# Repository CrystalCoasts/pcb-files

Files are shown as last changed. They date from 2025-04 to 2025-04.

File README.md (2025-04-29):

# Smart Sea Wall PCB Files
Repo for ESP32 Smart Sea Wall PCB and Hardware.  
***

## Table of Contents
- [Introduction](#introduction)
- [Getting Started](#getting-started)
- [Layout](#contains)
- [Bill of Materials](#bill-of-materials)
- [Installation](#installation)

***

## Introduction

We designed and created a PCB for easy recreation of the device. The sensors are plug and play, allowing the user to easily service the device. The file was desgined in KiCAD and printed using JLC PCB.

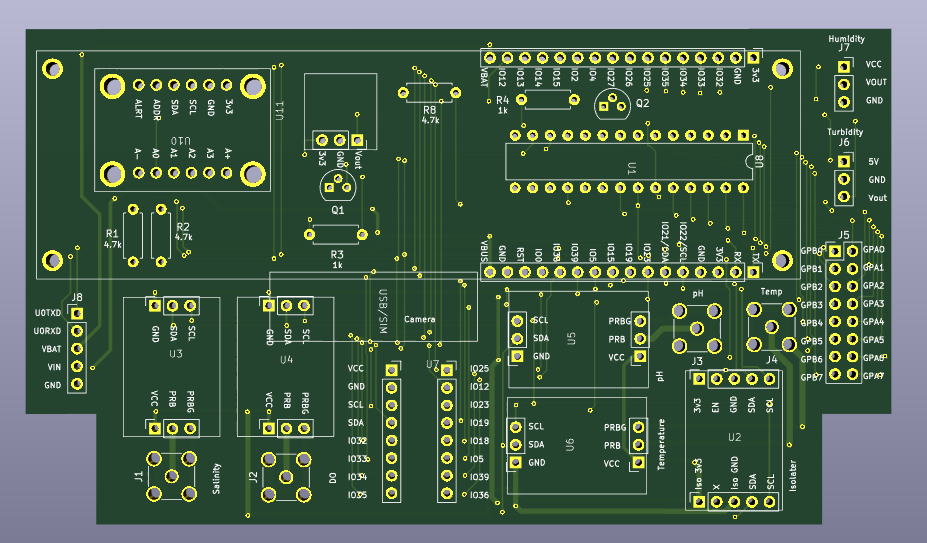
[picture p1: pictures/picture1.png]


***

## Getting Started

 1. Gather all components stated in the [BOM](#bill-of-materials).
 2. Order the PCB through JLCPCB using the already created gerber zip file.
 3. Follow the soldering and installation instructions in the [Instalation](#installation) section.
 4. Test device with the embedded-code repository.

## Bill of Materials

As far as materials go, many you may not be able to find headers the exact size for what you need. In that case, just find the closest one to it and cut it down to size (e.g. cut a 6 pin header to 5 pins), or use multiple to make up the size you need.

 - (8) 3-pin header
 - (4) SMA male connector
 - (2) 16-pin header
 - (2) 8-pin header
 - (1) 5-pin header
 - (2) 8-pin terminals (2.54 pitch)
 - (2) 3-pin terminals (2.54 pitch)
 - (3) 4.7k resistors (7.62 horizontal length)
 - (2) 1k resistors (7.62 horizontal length)
 - (2) bjt transistors (2n2222 or similar)
 - (1) mcp23017 I2C IO extender - [link](https://www.digikey.com/en/products/detail/microchip-technology/MCP23017-E-SP/894272)
 - (1) Boost converter - [link](https://a.co/d/0dH0B8B)
 - (1) I2C ADC - [link](https://www.adafruit.com/product/1083)
 - (1) Lilygo ESP32 T-7000G - [link](https://lilygo.cc/products/t-sim7000g?srsltid=AfmBOoofkf4orIAGPrCQvzU6p47uRy_uEcURHfCpysc8IG0x-OTQUHQe)

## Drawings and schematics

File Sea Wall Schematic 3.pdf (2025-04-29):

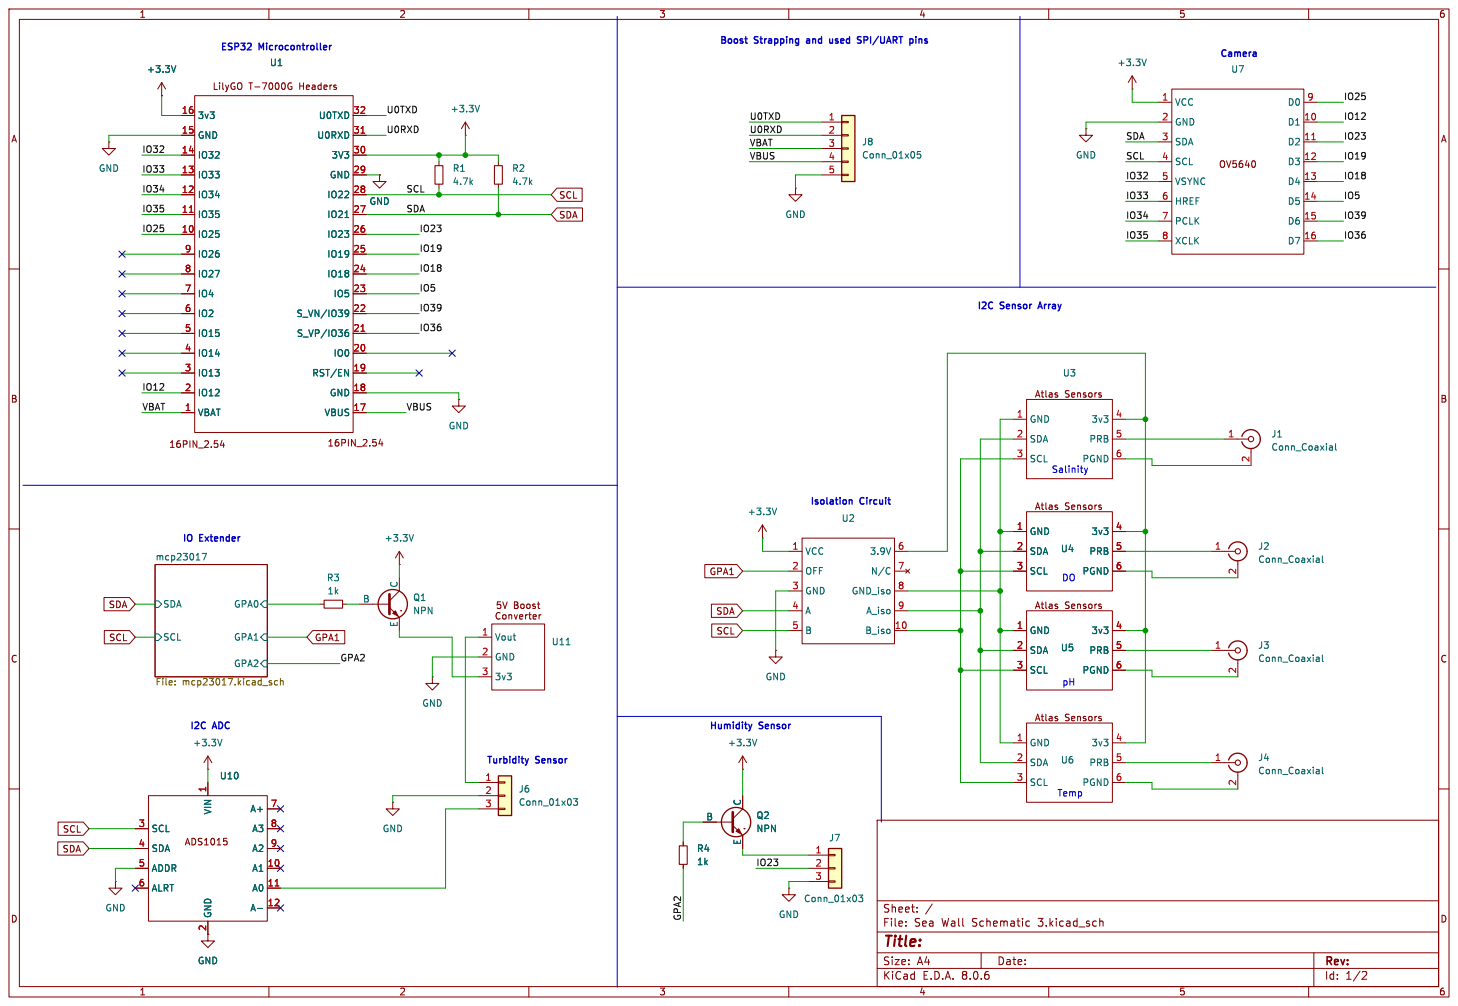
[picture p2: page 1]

Boost Strapping and used SPI/UART pins

Atlas Sensors GND 1 SDA 2 SCL 3
J2Conn_Coaxial 1 2

Isolation Circuit Turbidity Sensor

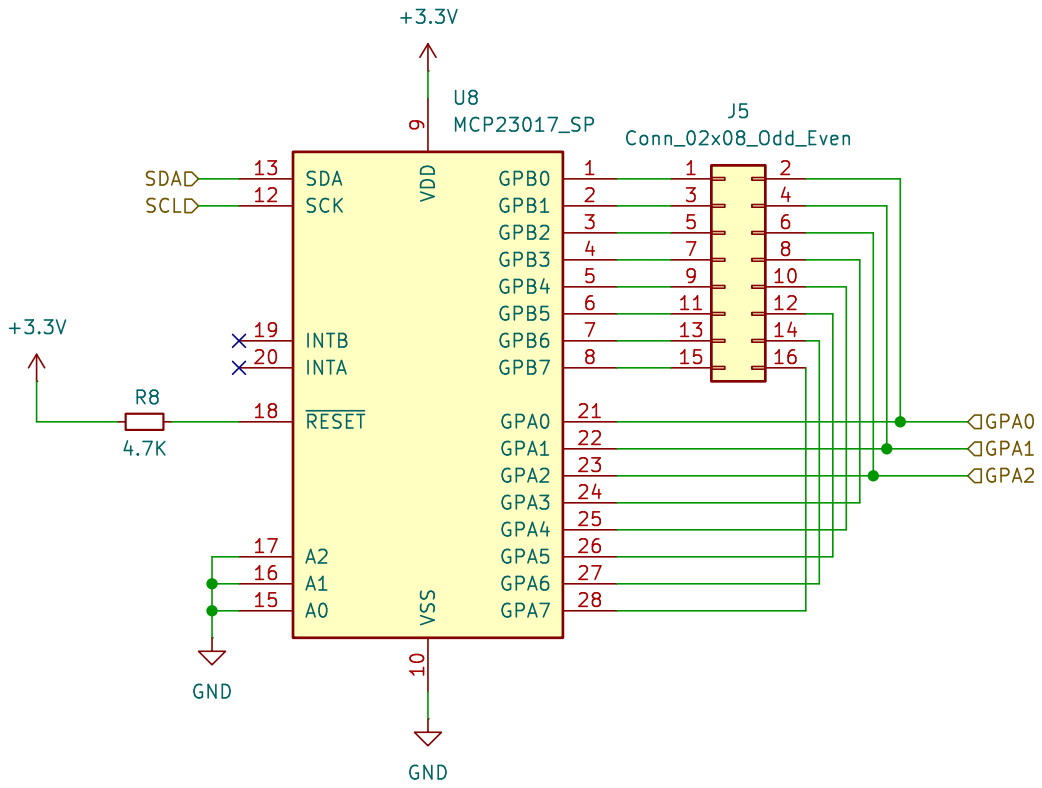
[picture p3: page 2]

11 | 12
13 | 14

Id: 3/2 Title: File: mcp23017.kicad_sch Sheet: /mcp23017/

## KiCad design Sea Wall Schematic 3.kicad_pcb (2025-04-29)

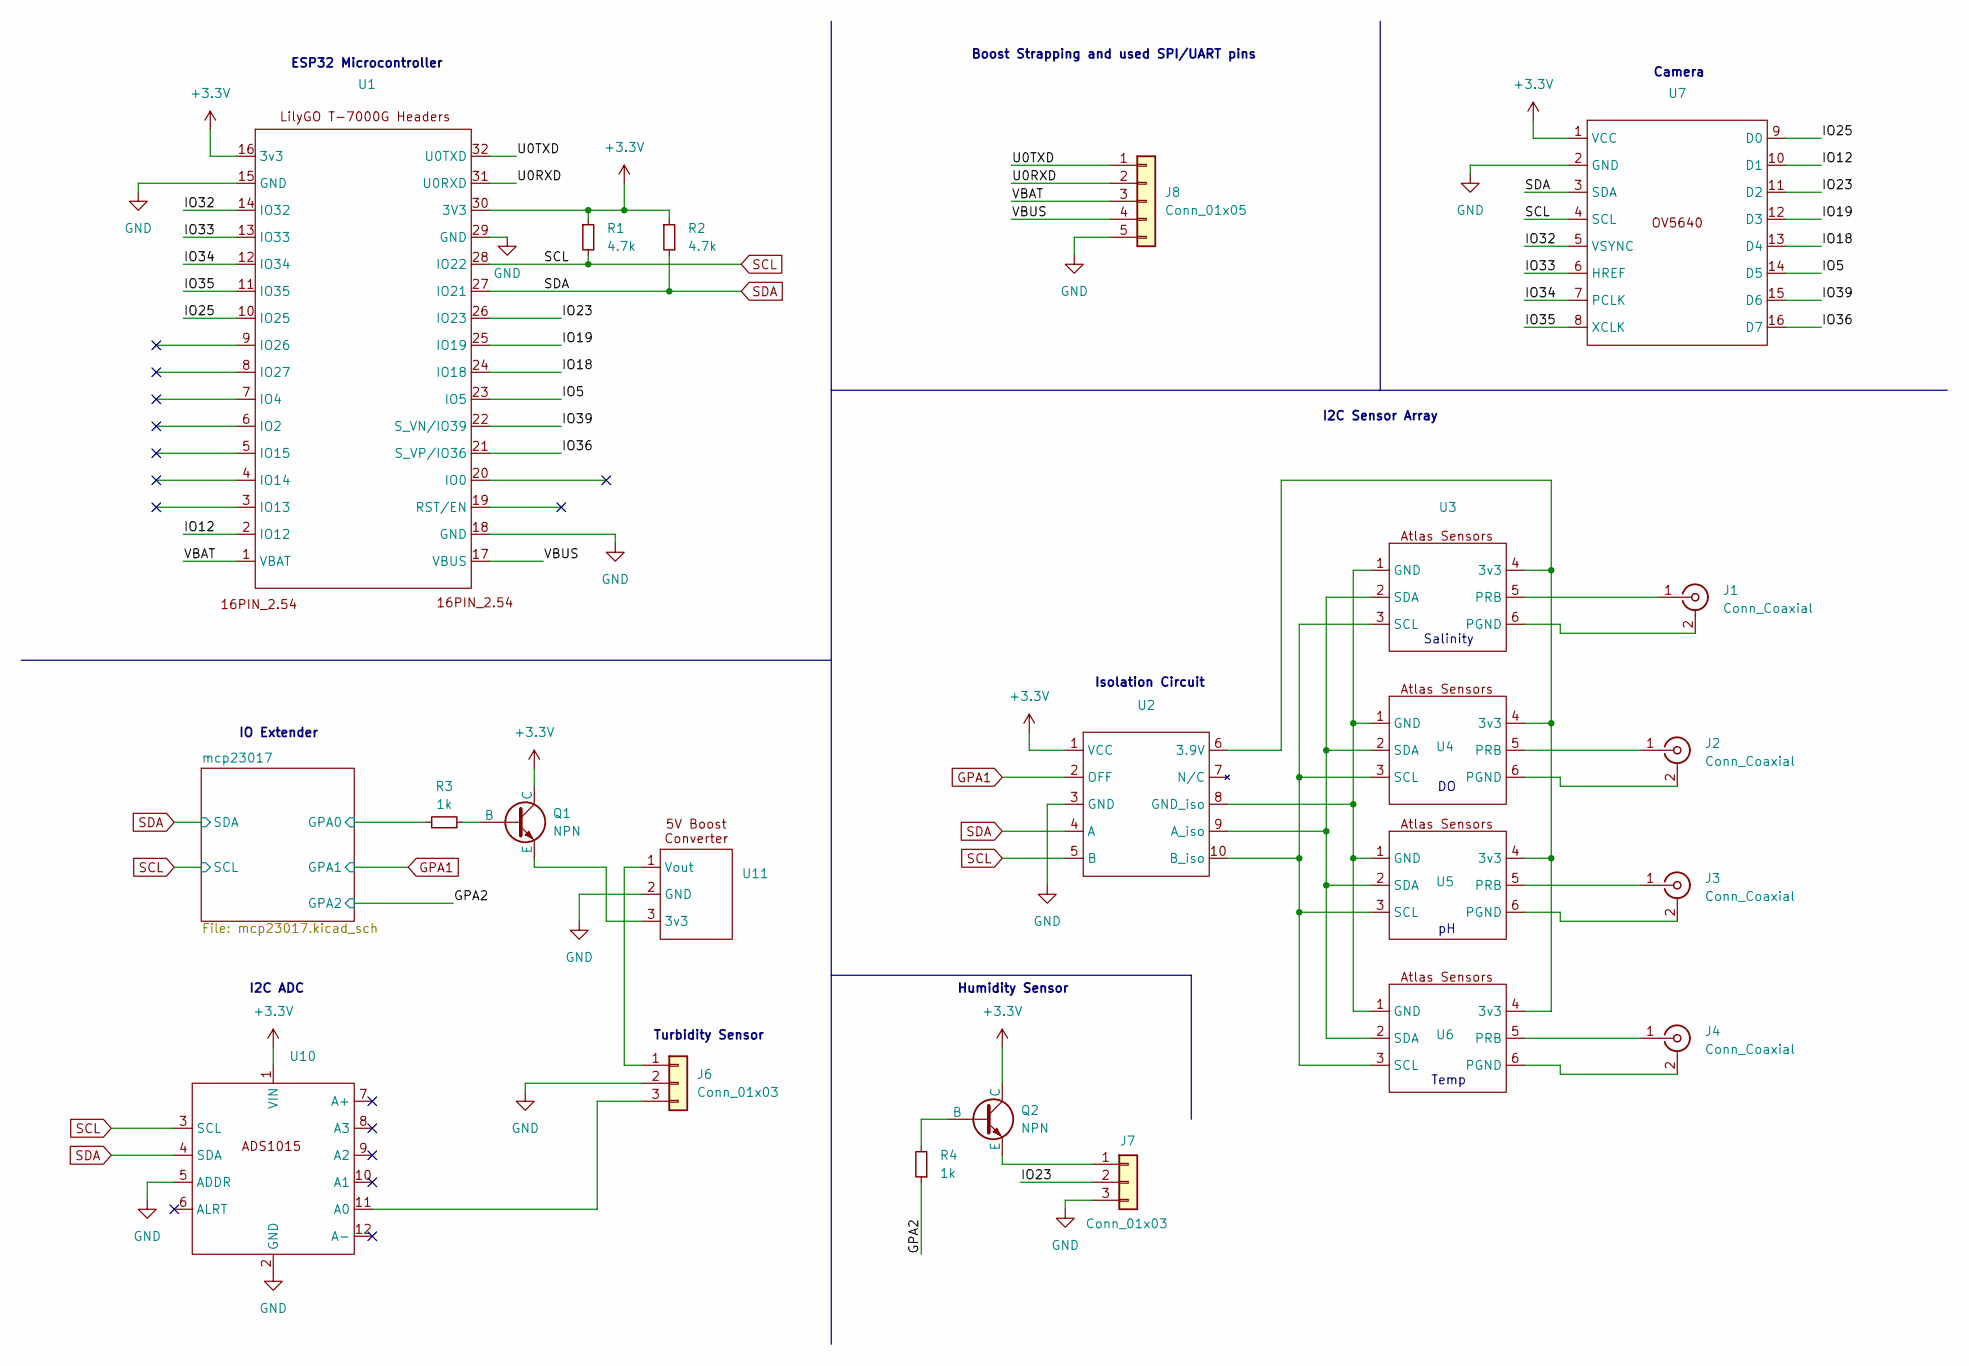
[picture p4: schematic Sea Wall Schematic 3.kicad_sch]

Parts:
J1, J2, J3, J4: Conn_Coaxial; SMA_Amphenol_901-144_Vertical
J6, J7: Conn_01x03; PinSocket_1x03_P2.54mm_Vertical
J8: Conn_01x05; PinHeader_1x05_P2.54mm_Vertical
Q1, Q2: NPN; TO-92
R1, R2: 4.7k; R_Axial_DIN0207_L6.3mm_D2.5mm_P7.62mm_Horizontal
R3, R4: 1k; R_Axial_DIN0207_L6.3mm_D2.5mm_P7.62mm_Horizontal
U1: T7000G
U2: isolation circuit
U3, U4, U5, U6: atlas-sensors
U7: OV5640
U10: AD1015
U11: boostconverter

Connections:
+3.3V: Q1.1 (C), Q2.1 (C), R1.1, R2.1, U1.16 (3v3), U1.30 (3V3), U2.1 (VCC), U7.1 (VCC), U10.1 (VIN); also elsewhere on the board
/GPA2: R4.1; also elsewhere on the board
/IO5: U1.23 (IO5), U7.14 (D5)
/IO12: U1.2 (IO12), U7.10 (D1)
/IO18: U1.24 (IO18), U7.13 (D4)
/IO19: U1.25 (IO19), U7.12 (D3)
/IO23: J7.2, U1.26 (IO23), U7.11 (D2)
/IO25: U1.10 (IO25), U7.9 (D0)
/IO32: U1.14 (IO32), U7.5 (VSYNC)
/IO33: U1.13 (IO33), U7.6 (HREF)
/IO34: U1.12 (IO34), U7.7 (PCLK)
/IO35: U1.11 (IO35), U7.8 (XCLK)
/IO36: U1.21 (S_VP/IO36), U7.16 (D7)
/IO39: U1.22 (S_VN/IO39), U7.15 (D6)
/U0RXD: J8.2, U1.31 (U0RXD)
/U0TXD: J8.1, U1.32 (U0TXD)
/VBAT: J8.3, U1.1 (VBAT)
/VBUS: J8.4, U1.17 (VBUS)
/mcp23017/GPA0: R3.1; also elsewhere on the board
GND: J6.2, J7.3, J8.5, U1.15 (GND), U1.18 (GND), U1.29 (GND), U2.3 (GND), U7.2 (GND), U10.2 (GND), U10.5 (ADDR), U11.2 (GND); also elsewhere on the board
GPA1: U2.2 (OFF); also elsewhere on the board
unnamed: J1.2 (Ext), U3.6 (PGND)
unnamed: J1.1 (In), U3.5 (PRB)
unnamed: J2.2 (Ext), U4.6 (PGND)
unnamed: J2.1 (In), U4.5 (PRB)
unnamed: J3.2 (Ext), U5.6 (PGND)
unnamed: J3.1 (In), U5.5 (PRB)
unnamed: J4.2 (Ext), U6.6 (PGND)
unnamed: J4.1 (In), U6.5 (PRB)
unnamed: J6.1, U11.1 (Vout)
unnamed: J6.3, U10.11 (A0)
unnamed: J7.1, Q2.3 (E)
unnamed: Q1.2 (B), R3.2
unnamed: Q1.3 (E), U11.3 (3v3)
unnamed: Q2.2 (B), R4.2
unnamed: U2.6 (3.9V), U3.4 (3v3), U4.4 (3v3), U5.4 (3v3), U6.4 (3v3)
unnamed: U2.9 (A_iso), U3.2 (SDA), U4.2 (SDA), U5.2 (SDA), U6.2 (SDA)
unnamed: U2.10 (B_iso), U3.3 (SCL), U4.3 (SCL), U5.3 (SCL), U6.3 (SCL)
unnamed: U2.8 (GND_iso), U3.1 (GND), U4.1 (GND), U5.1 (GND), U6.1 (GND)
SCL: R1.2, U1.28 (IO22), U2.5 (B), U7.4 (SCL), U10.3 (SCL); also elsewhere on the board
SDA: R2.2, U1.27 (IO21), U2.4 (A), U7.3 (SDA), U10.4 (SDA); also elsewhere on the board

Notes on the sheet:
Camera
Humidity Sensor
ESP32 Microcontroller
Isolation Circuit
Temp
Boost Strapping and used SPI/UART pins
Turbidity Sensor
IO Extender
I2C Sensor Array
Salinity
I2C ADC

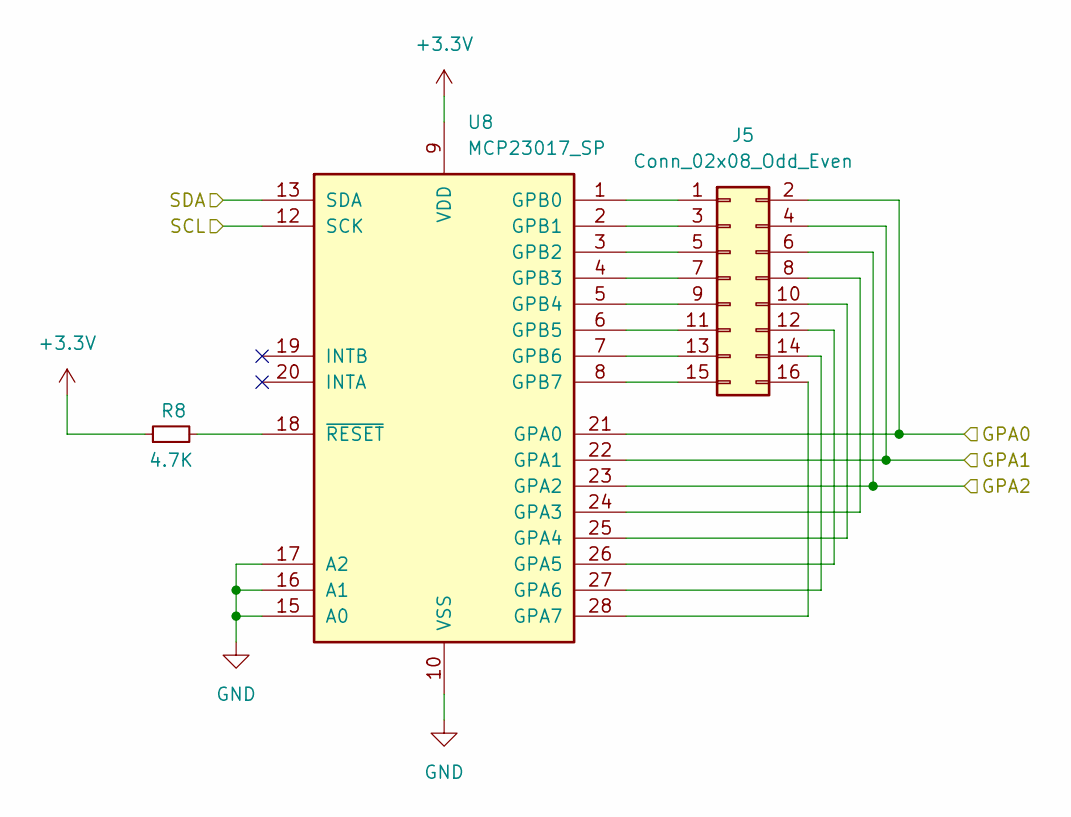
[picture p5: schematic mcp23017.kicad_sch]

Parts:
J5: Conn_02x08_Odd_Even; PinHeader_2x08_P2.54mm_Vertical
R8: 4.7K; R_Axial_DIN0207_L6.3mm_D2.5mm_P7.62mm_Horizontal
U8: MCP23017_SP; DIP-28_W7.62mm

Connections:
+3.3V: R8.1, U8.9 (VDD); also elsewhere on the board
/GPA2: J5.6, U8.23 (GPA2); also elsewhere on the board
/mcp23017/GPA0: J5.2, U8.21 (GPA0); also elsewhere on the board
GND: U8.10 (VSS), U8.15 (A0), U8.16 (A1), U8.17 (A2); also elsewhere on the board
GPA1: J5.4, U8.22 (GPA1); also elsewhere on the board
unnamed: J5.1, U8.1 (GPB0)
unnamed: J5.3, U8.2 (GPB1)
unnamed: J5.5, U8.3 (GPB2)
unnamed: J5.7, U8.4 (GPB3)
unnamed: J5.8, U8.24 (GPA3)
unnamed: J5.9, U8.5 (GPB4)
unnamed: J5.10, U8.25 (GPA4)
unnamed: J5.11, U8.6 (GPB5)
unnamed: J5.12, U8.26 (GPA5)
unnamed: J5.13, U8.7 (GPB6)
unnamed: J5.14, U8.27 (GPA6)
unnamed: J5.15, U8.8 (GPB7)
unnamed: J5.16, U8.28 (GPA7)
unnamed: R8.2, U8.18 (~RESET)
SCL: U8.12 (SCK); also elsewhere on the board
SDA: U8.13 (SDA); also elsewhere on the board

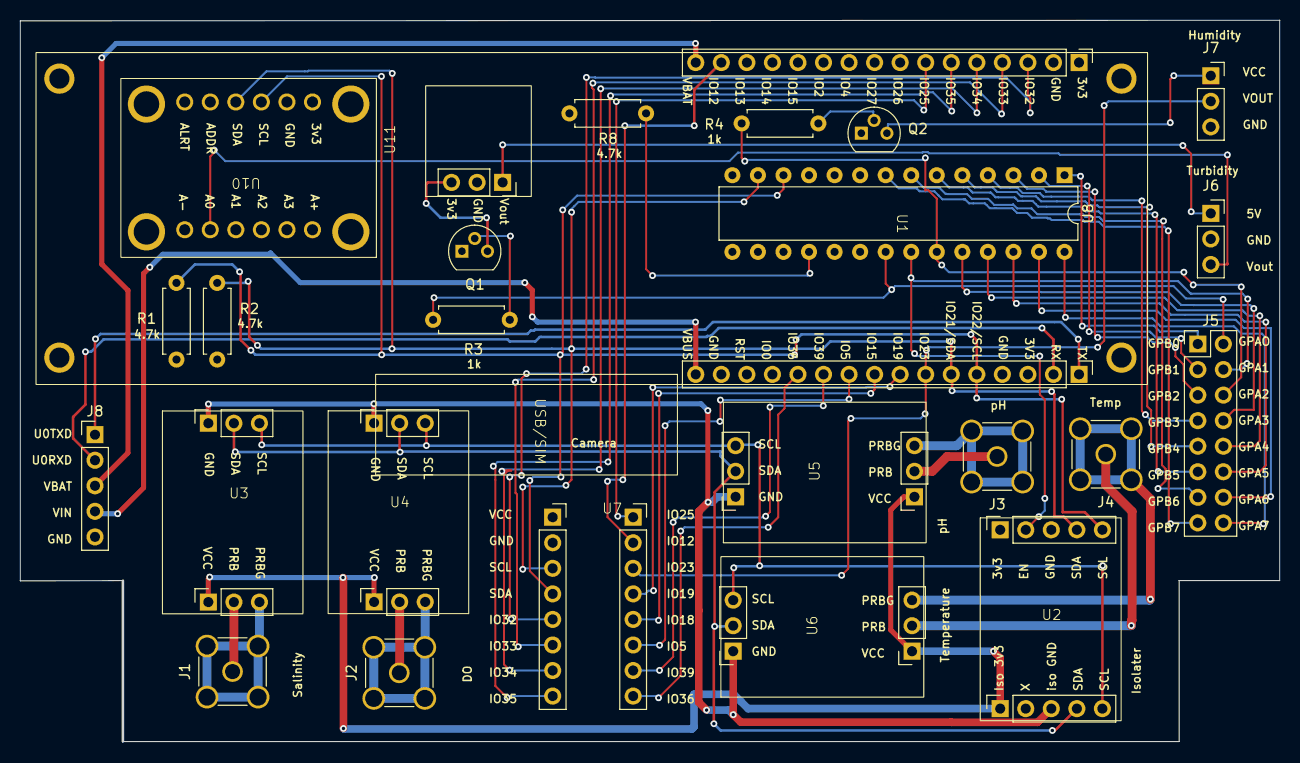
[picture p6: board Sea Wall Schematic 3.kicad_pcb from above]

Board: 4 copper layers, 125.2 x 71.7 mm, 25 parts (0 on the bottom side), 55 nets.

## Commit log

2024-12-04 PCB files for reproducing (Made in KiCad8)
    [Sea Wall Schematic2.kicad_pcb, Sea Wall Schematic2.kicad_sch]
2024-12-04 PCB Schematic PDF
2025-04-29 Updated PCB files from KiCAD
    updated gerbers and added zip files for the new schematic
    [Sea Wall Schematic 3-B_Mask.gbs, Sea Wall Schematic 3-B_Paste.gbp, Sea Wall Schematic 3-B_Silkscreen.gbo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]
